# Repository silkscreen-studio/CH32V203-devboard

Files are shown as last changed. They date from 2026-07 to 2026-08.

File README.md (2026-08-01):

# CH32V203 devboard

A simple CH32V203C8U6 devboard, with a 7x8 charlieplexed matrix and a 12P FPC for IOs, beside the more common 2.54 headers for breadboard compatibility.
<br></br>

ZINE V1 1

# Key features 
 - CH32V203C8U6 MCU:
    - FLASH: 64k (+224K non-zero-wait program memory)
    - SRAM: 20k
    - 144MHz CPU max clock speed
    - 37 GPIOs
    - Many peripherals (4x USART, 2x SPI, 2x I2C, 1x CAN, USB (FS))
    - 9 analog capable GPIOs
    - 12 PWM capable GPIOs
 - USB-C for programming, USB device/host emulation, and power
 - 7x8 charlieplexed LED matrix (8 GPIOs)
 - 23x 2.54mm header pins
 - 12P .5mm FPC for breaking out 9 more IOs
 - Boot and Reset Button
 - On board 3.3V LDO `TLV75733PDBVR`, 1A max current

Demo with the charlieplexed LED matrix in action:
https://youtube.com/shorts/uVbg5wJzLvo
<br></br>

<p align="center">
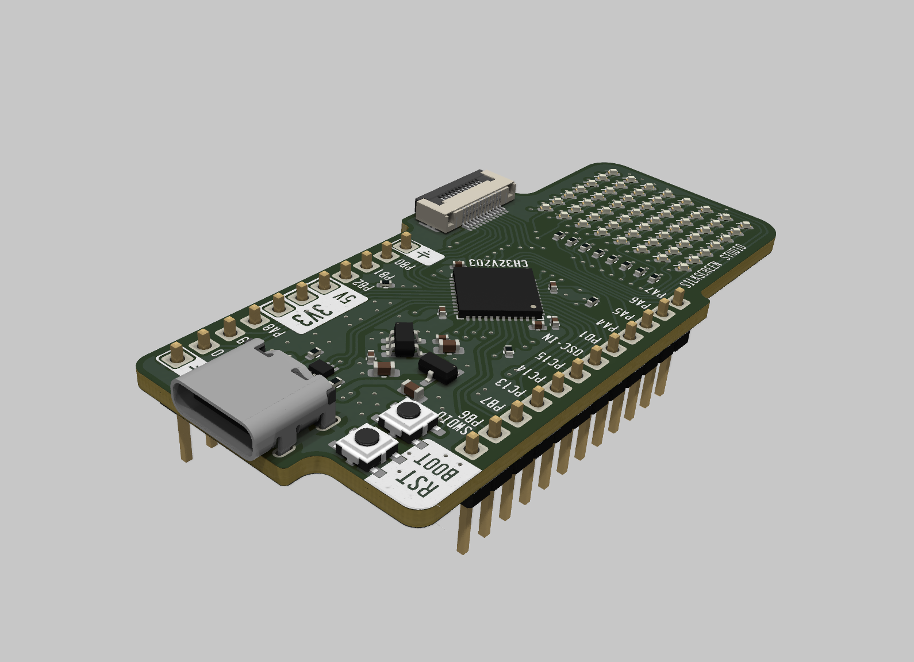
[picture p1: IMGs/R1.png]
Render 1

</p>
<p align="center">
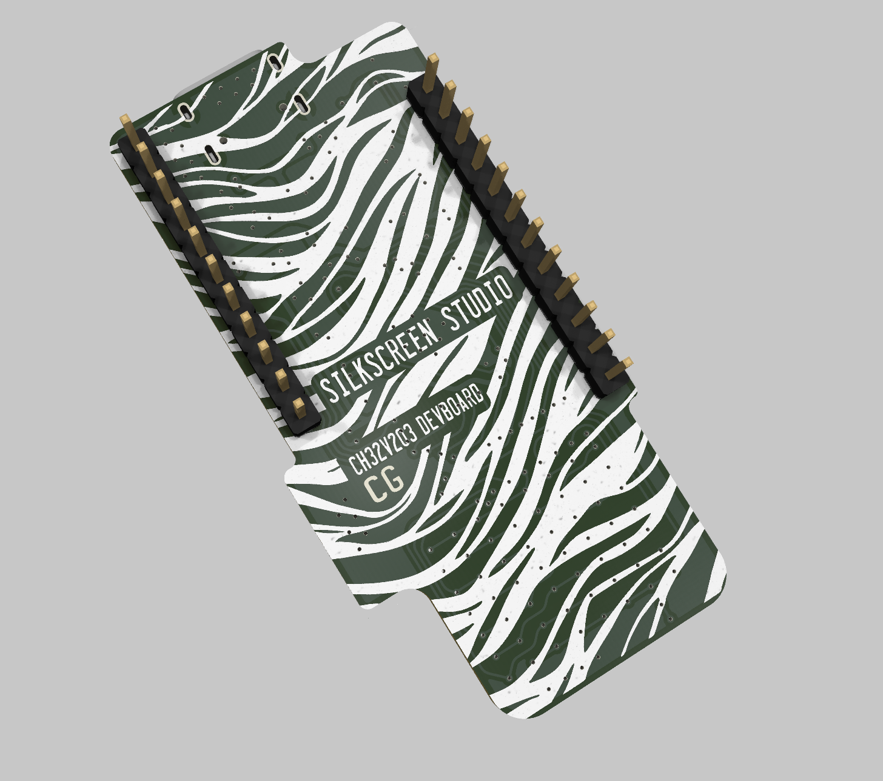
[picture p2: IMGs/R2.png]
Render 2
  
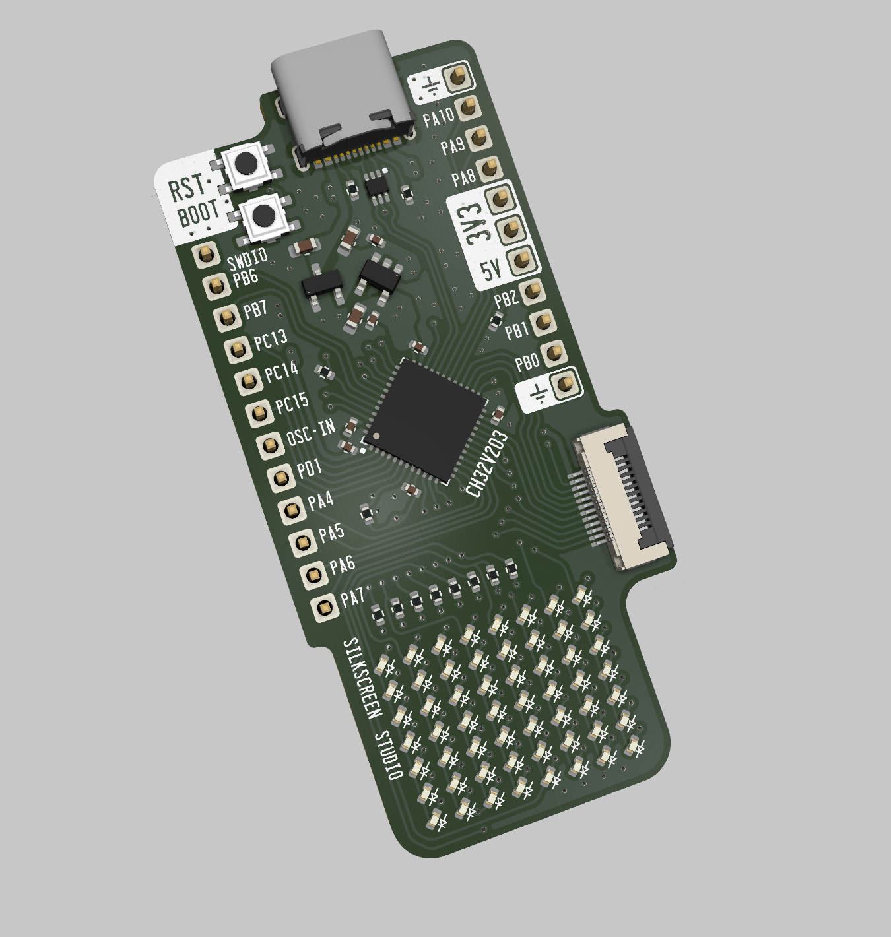
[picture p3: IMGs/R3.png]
Render 3
  
</p>

<p align="center">
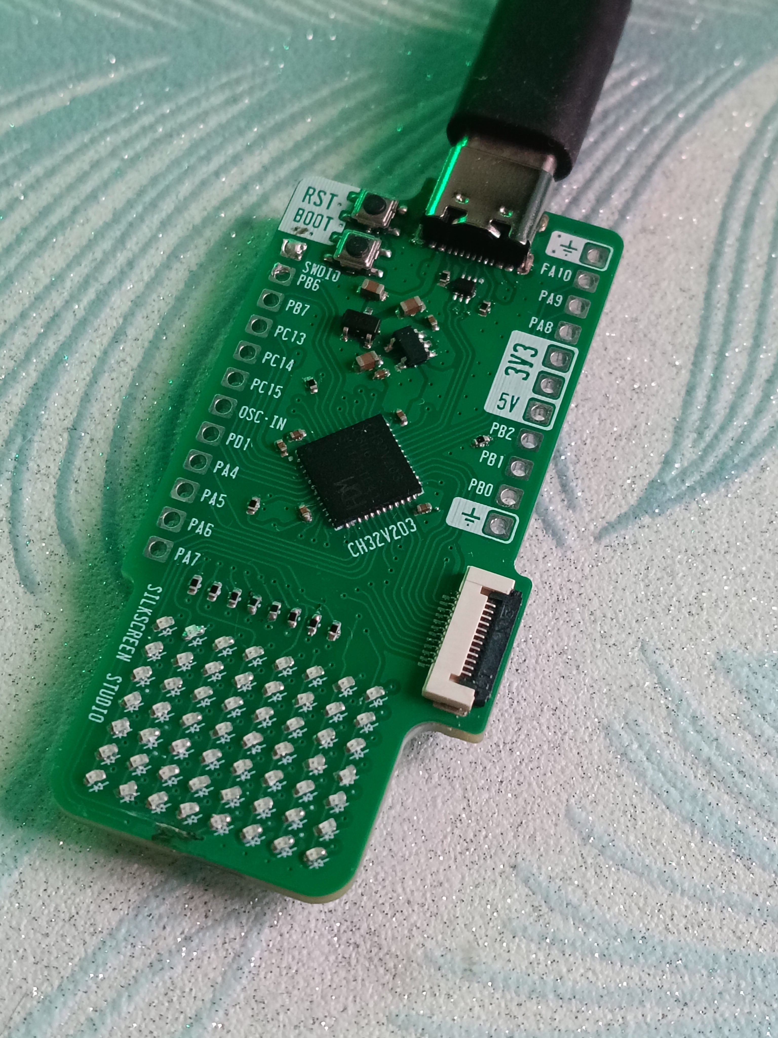
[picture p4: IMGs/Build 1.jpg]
Build 1

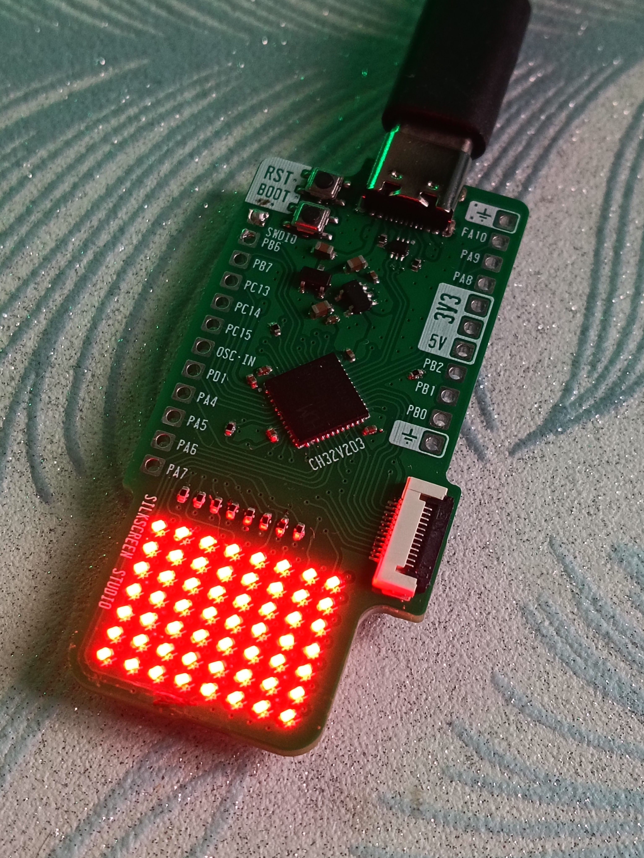
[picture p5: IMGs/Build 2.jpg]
Build 1

</p>

<br></br>

# Schematic
SCHEMATIC
<br></br>

# PCB layout
<p align="center">
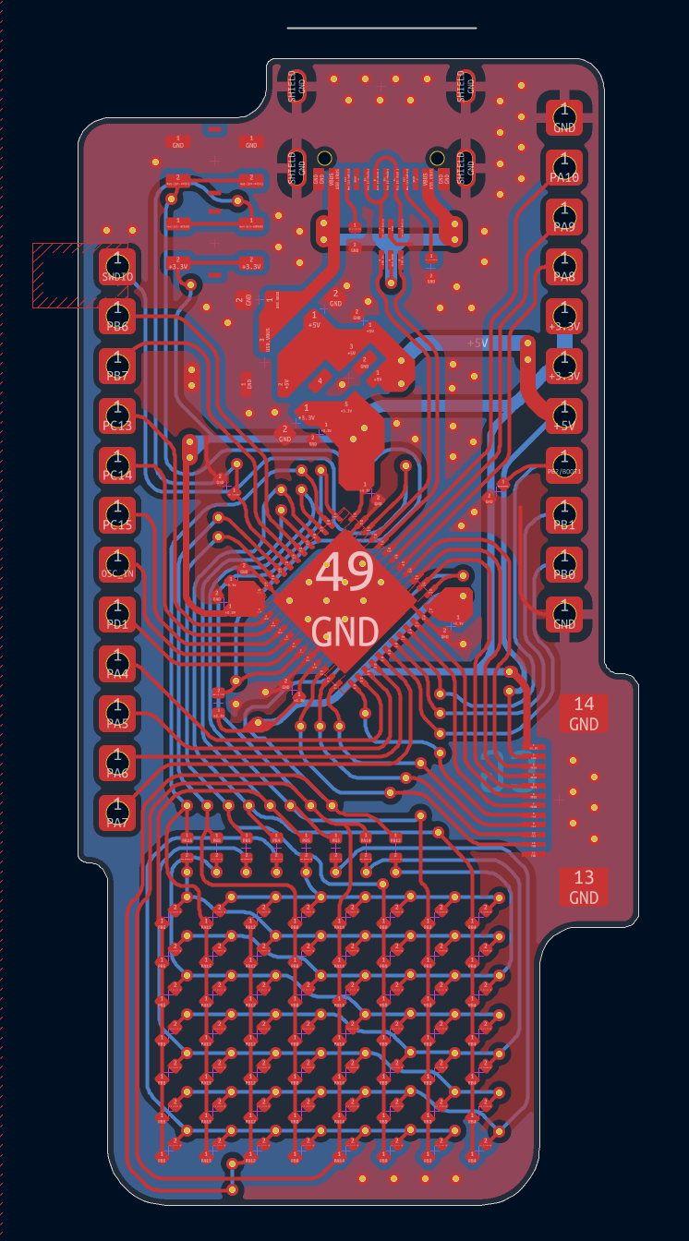
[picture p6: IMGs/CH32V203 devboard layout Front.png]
Layout F
  
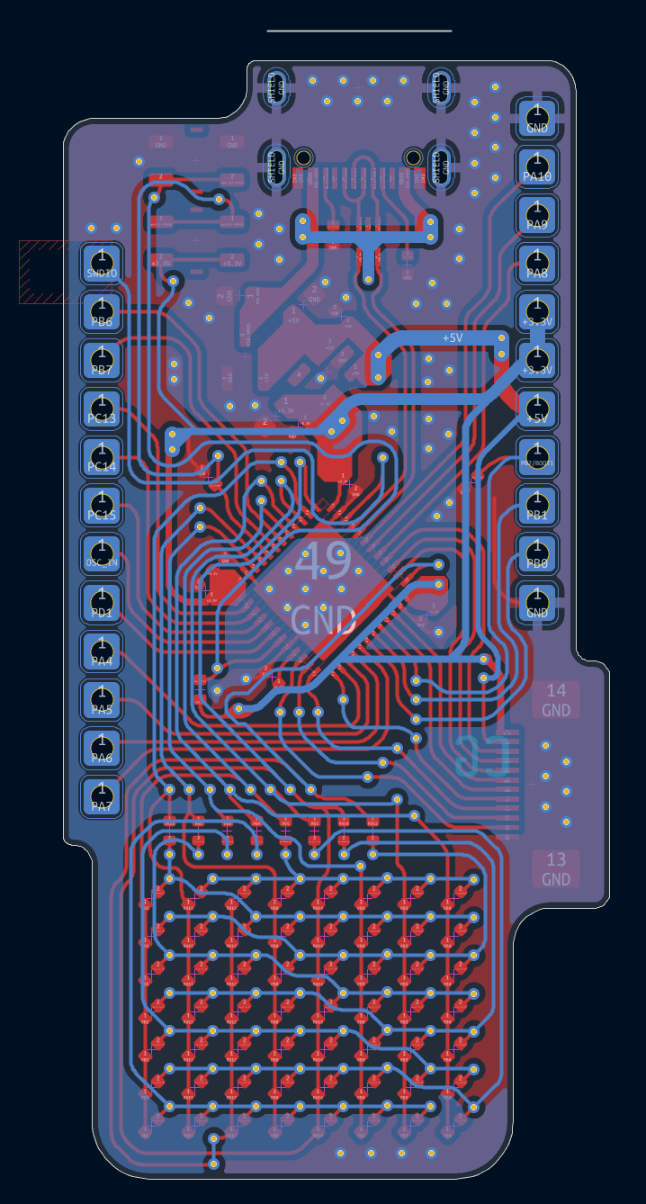
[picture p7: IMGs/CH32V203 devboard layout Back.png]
Layout B
  
</p>
<br></br>

# Pinout

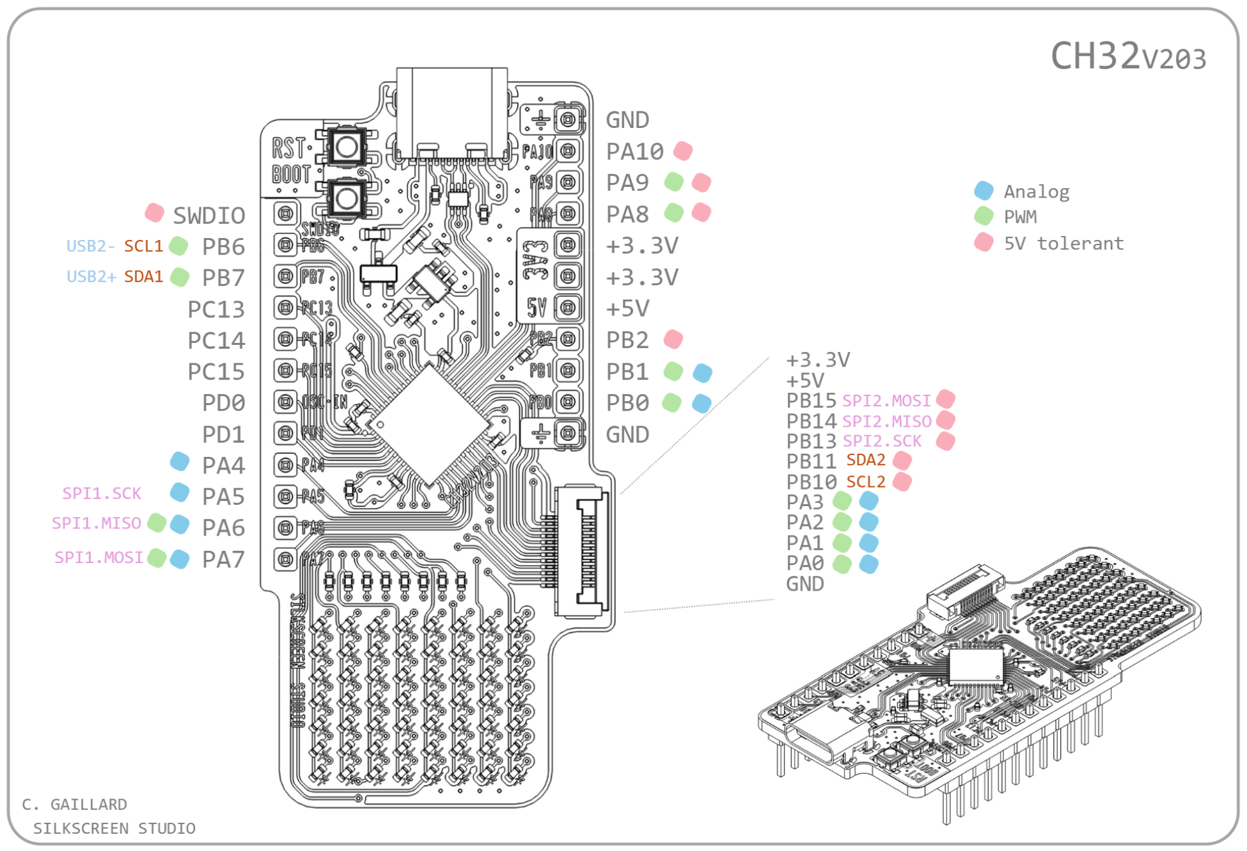
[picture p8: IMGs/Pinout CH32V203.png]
Pinout

<br></br>

# BOM

| Qty | Type | Part | Value | Extended description | Unit price | Price [MOQ]| LCSC part number | Link |
| --- | --- | --- | --- | --- | --- | --- | --- | --- |
| 7 | MLCC | CL05B104KB54PNC | 100nF | 0402 | $0.014 | $1.40 [100] | C307331 | https://www.lcsc.com/product-detail/C307331.html |
| 3 | MLCC | CL10A106MA8NRNC | 10µF | 0603 | $0.14 | $2.80 [20] | C96446 | https://www.lcsc.com/product-detail/C96446.html |
| 1 | Ideal Diode | CH213K | |  | $0.074 | $0.74 [10] | C5456874 | https://www.lcsc.com/product-detail/C5456874.html |
| 1 | FPC connector 12P | FPC-05F-12PH20 | |  | $0.11 | $0.57 [5] | C2856799 | https://www.lcsc.com/product-detail/C2856799.html |
| 56 | LED | XL-1005UOC | | Orange 0402 LED | $0.014 | $1.42 [100] | C965791 | https://www.lcsc.com/product-detail/C965791.html |
| 3 | Resistor | RC0402JR-7W10KL | 10k | 0402 SMD resistor | $0.004 | $0.45 [100] | C851859 | https://www.lcsc.com/product-detail/C851859.html |
| 2 | Resistor | RC-02K512JT | 5.1k | 0402 SMD resistor | $0.0033 | $0.33 [100] | C453708 | https://www.lcsc.com/product-detail/C453708.html |
| 8 | Resistor | RC0402FR-07680RL | 680 | 0402 SMD resistor | $0.0014 | $0.14 [100] | C137948 | https://www.lcsc.com/product-detail/C137948.html |
| 2 | Push button | TS-1075S-A1B2-D4 | | | $0.066 | $0.66 [10] | C492872 | https://www.lcsc.com/product-detail/C492872.html |
| 1 | MCU | CH32V203C8U6 | | | $0.85 | $0.85 [1] | C6407762 | https://www.lcsc.com/product-detail/C6407762.html |
| 1 | LDO | TLV75733PDBVR | | 3.3V LDO | $0.18 | $0.92 [5] | C485517 | https://www.lcsc.com/product-detail/C485517.html |
| 1 | ESD protection | USBLC6-2P6 | | | $0.28 | $1.39 [5] | C15999 | https://www.lcsc.com/product-detail/C15999.html |
| 1 | PCB | | | | $5 |  |  | https://jlcpcb.com/quote |
|  |  |  |  |  |  |  |  |  |
|  | TOTAL (price per board) | | | | $7.96 |  |  |  |
|  | TOTAL (price due to MOQ) | | | | $16.67 |  |  |  |

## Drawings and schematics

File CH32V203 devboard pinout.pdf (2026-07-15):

## CH32V203

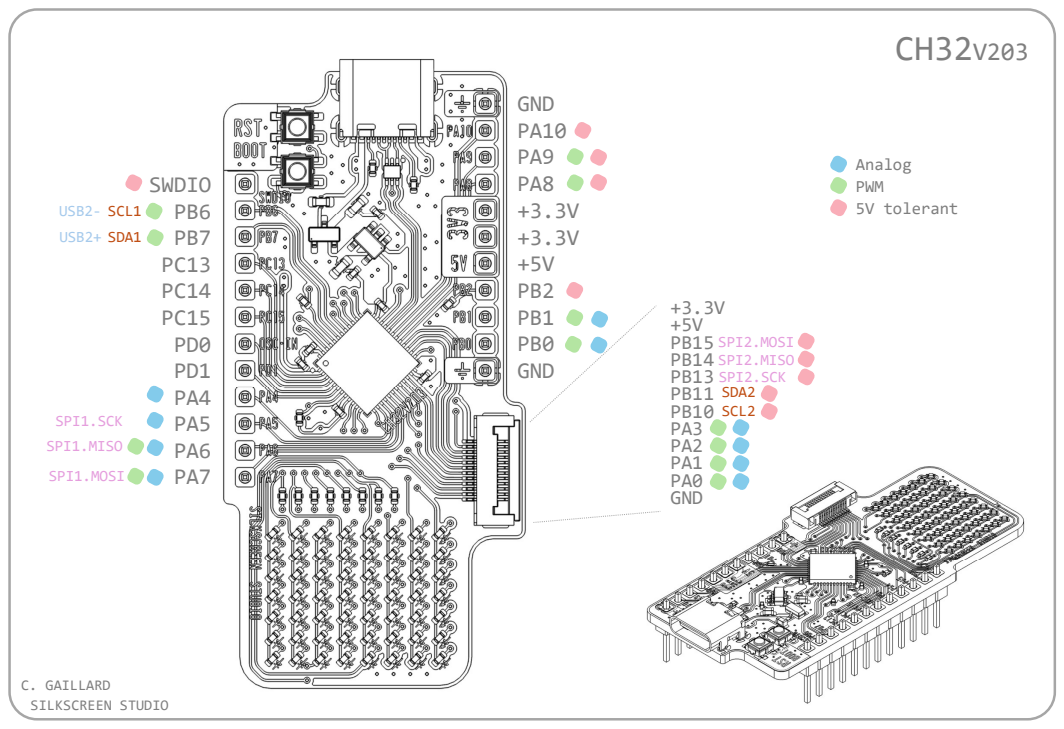
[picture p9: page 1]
GND; 5V tolerant; PWM; Analog; SILKSCREEN STUDIO; C. GAILLARD; PB2 PB1 PB0 GND; SWDIO PB6 PB7 PC13 PC14 PC15 PD0 PD1 PA4 PA5 PA6 PA7; +3.3V +5V PB15 PB14 PB13 PB11 PB10 PA3 PA2 PA1 PA0 GND; SDA2 SCL2; SDA1; USB2- SCL1 USB2+; SPI2.MOSI SPI2.MISO SPI2.SCK; SPI1.MOSI; SPI1.MISO; SPI1.SCK

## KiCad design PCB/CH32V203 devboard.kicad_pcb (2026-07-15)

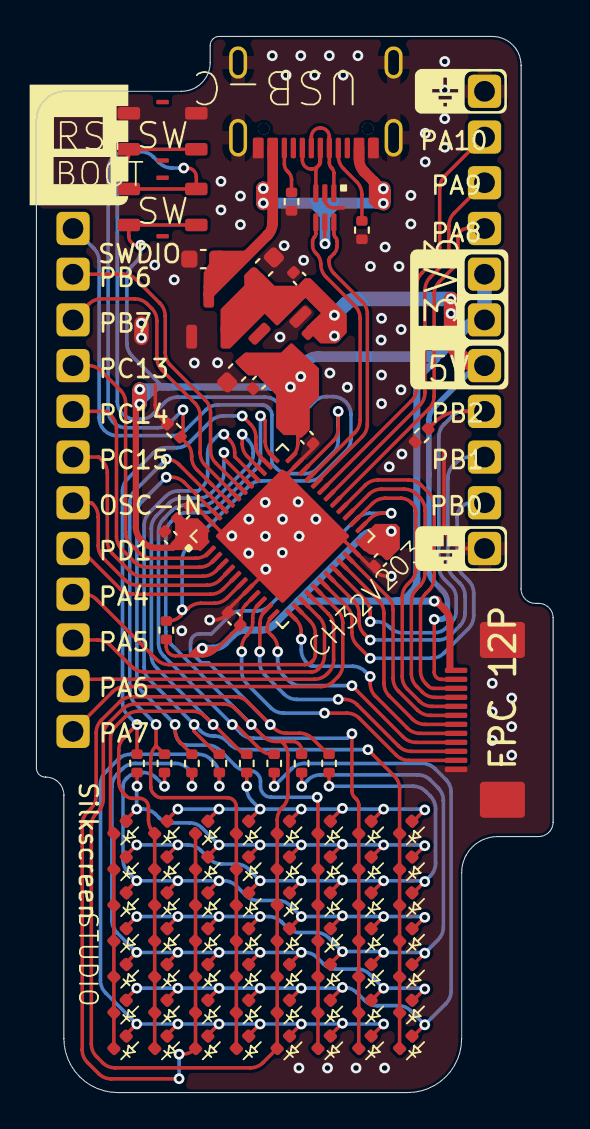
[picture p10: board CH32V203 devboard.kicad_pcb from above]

Board: 2 copper layers, 28.7 x 58.7 mm, 110 parts (0 on the bottom side), 55 nets.

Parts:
C1, C2, C3, C4, C5, C6, C9: 100nF; C_0402_1005Metric
C7, C8, C10: 10uF; C_0603_1608Metric
D1: SOT-23-3
FPC1: FPC 12P Custom footprint C2856799
J1: USB C connector USB2.0 16P; USB_C_16P_custom_footprint_C2765186
LED2, LED3, LED4, LED5, LED6, LED7, LED8, LED9, LED11, LED12, LED13, LED14, LED15, LED16, LED17, LED18, LED20, LED21, LED22, LED23, LED24, LED25, LED26, LED27, LED29, LED30, LED31, LED32, LED33, LED34, LED35, LED36, LED38, LED39, LED40, LED41, LED42, LED43, LED44, LED45, LED47, LED48, LED49, LED50, LED51, LED52, LED53, LED54, LED56, LED57, LED58, LED59, LED60, LED61, LED62, LED63: LED; CUSTOM LED_0402_1005Metric
P1, P2, P3, P4, P5, P6, P7, P8, P9, P10, P12, P13, P18, P19, P20, P21, P22, P23, P26, P27, P28, P29, P30: Custom 1P 2.54mm header
R1, R2, R3: 10k; R_0402_1005Metric
R4, R5: 5.1k; R_0402_1005Metric
R6, R7, R8, R9, R10, R11, R12, R13: 680; R_0402_1005Metric
SW1, SW2: SW_Push; switch_custom_footprint_TS-1075S-A1B2-D4_C492872.pretty
U1: CUSTOM_QFN-48-1EP_7x7mm_P0.5mm_EP5.3x5.3mm
U2: SOT-23-5
U3: USBLC6-2P6; USB ESD SOT666 C15999

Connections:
+3.3V: C1.1, C2.1, C3.1, C4.1, C5.1, C8.1, C9.1, FPC1.1, P18.1, P19.1, R1.1, SW2.2, U1.1 (VBAT), U1.9 (VDDA), U1.24 (VDD_VIO_1), U1.36 (VDD_2), U1.48 (VDD_VIO_3), U2.5 (OUT)
+5V: C6.1, C7.1, D1.2 (OUT+), FPC1.2, P20.1, U2.1 (IN), U2.3 (EN)
/USB.VBUS: C10.1, D1.3 (IN+), J1.VBUS (VBUS_VBUS), U3.5 (VBUS)
GND: C1.2, C2.2, C3.2, C4.2, C5.2, C6.2, C7.2, C8.2, C9.2, C10.2, D1.1 (GND), FPC1.12, FPC1.13 (SH1), FPC1.14 (SH2), J1.GND (GND_GND), J1.SHIELD (SHIELD_SH), P12.1, P13.1, R2.2, R3.2, R4.2, R5.2, SW1.1, U1.8 (VSSA), U1.23 (VSS_1), U1.35 (VSS_2), U1.47 (VSS_3), U1.49 (VSS), U2.2 (GND), U3.2 (GND)
unnamed: J1.CC1 (CC1_CC1), R5.1
unnamed: J1.CC2 (CC2_CC2), R4.1
unnamed: J1.D+ (D+_D+), U3.3 (I/O2)
unnamed: J1.D- (D-_D-), U3.1 (I/O1)
unnamed: LED3.2 (A), LED11.2 (A), LED27.2 (A), LED35.2 (A), LED43.2 (A), LED51.2 (A), LED59.2 (A), R8.2
unnamed: LED4.2 (A), LED12.2 (A), LED20.2 (A), LED36.2 (A), LED44.2 (A), LED52.2 (A), LED60.2 (A), R9.2
unnamed: LED5.2 (A), LED13.2 (A), LED21.2 (A), LED29.2 (A), LED45.2 (A), LED53.2 (A), LED61.2 (A), R10.2
unnamed: LED6.2 (A), LED14.2 (A), LED22.2 (A), LED30.2 (A), LED38.2 (A), LED54.2 (A), LED62.2 (A), R11.2
unnamed: LED7.2 (A), LED15.2 (A), LED23.2 (A), LED31.2 (A), LED39.2 (A), LED47.2 (A), LED63.2 (A), R12.2
unnamed: LED8.2 (A), LED16.2 (A), LED24.2 (A), LED32.2 (A), LED40.2 (A), LED48.2 (A), LED56.2 (A), R13.2
unnamed: LED9.2 (A), LED17.2 (A), LED25.2 (A), LED33.2 (A), LED41.2 (A), LED49.2 (A), LED57.2 (A), R6.2
unnamed: LED2.2 (A), LED18.2 (A), LED26.2 (A), LED34.2 (A), LED42.2 (A), LED50.2 (A), LED58.2 (A), R7.2
unnamed: R2.1, SW2.1, U1.44 (BOOT0)
unnamed: R1.2, SW1.2, U1.7 (NRST)
OSC_IN: P4.1, U1.5 (OSC_IN/PD0)
PA0: FPC1.11, U1.10 (PA0/WKUP/ADC0/TIM2_CH1)
PA1: FPC1.10, U1.11 (PA1/ADC1/TIM2_CH2)
PA2: FPC1.9, U1.12 (PA2/ADC2/TIM2_CH3/TX2)
PA3: FPC1.8, U1.13 (PA3/ADC3/TIM2_CH4/RX2)
PA4: P6.1, U1.14 (PA4/ADC4)
PA5: P7.1, U1.15 (PA5/ADC5/SPI1_SCK)
PA6: P8.1, U1.16 (PA6/ADC6/SPI1_MISO/TIM3_CH1)
PA7: P9.1, U1.17 (PA7/ADC7/SPI1_MOSI/TIM3_CH2)
PA8: P26.1, U1.29 (TIM1_CH1/PA8)
PA9: P27.1, U1.30 (TX1/TIM1_CH2/PA9)
PA10: P28.1, U1.31 (RX1/TIM1_CH3/PA10)
PA14: LED33.1 (K), LED34.1 (K), LED35.1 (K), LED36.1 (K), LED38.1 (K), LED39.1 (K), LED40.1 (K), R10.1, U1.37 (SWCLK/PA14)
PA15: LED9.1 (K), LED11.1 (K), LED12.1 (K), LED13.1 (K), LED14.1 (K), LED15.1 (K), LED16.1 (K), R7.1, U1.38 (PA15)
PB0: P21.1, U1.18 (PB0/ADC8/TIM3_CH3/TX4)
PB1: P22.1, U1.19 (PB1/ADC9/TIM3_CH4/RX4)
PB2/BOOT1: P10.1, R3.1, U1.20 (PB2/BOOT1)
PB3: LED49.1 (K), LED50.1 (K), LED51.1 (K), LED52.1 (K), LED53.1 (K), LED54.1 (K), LED56.1 (K), R12.1, U1.39 (PB3)
PB4: LED57.1 (K), LED58.1 (K), LED59.1 (K), LED60.1 (K), LED61.1 (K), LED62.1 (K), LED63.1 (K), R13.1, U1.40 (PB4)
PB5: LED2.1 (K), LED3.1 (K), LED4.1 (K), LED5.1 (K), LED6.1 (K), LED7.1 (K), LED8.1 (K), R6.1, U1.41 (PB5)
PB6: P29.1, U1.42 (TIM4_CH1/SCL1/PB6/USB2DM)
PB7: P30.1, U1.43 (TIM4_CH2/SDA1/PB7/USB2DP)
PB8: LED25.1 (K), LED26.1 (K), LED27.1 (K), LED29.1 (K), LED30.1 (K), LED31.1 (K), LED32.1 (K), R9.1, U1.45 (TIM4_CH3/PB8)
PB9: LED41.1 (K), LED42.1 (K), LED43.1 (K), LED44.1 (K), LED45.1 (K), LED47.1 (K), LED48.1 (K), R11.1, U1.46 (TIM4_CH4/PB9)
PB10: FPC1.7, U1.21 (PB10/SCL2/TX3)
PB11: FPC1.6, U1.22 (PB11/SDA2/RX3)
PB12: LED17.1 (K), LED18.1 (K), LED20.1 (K), LED21.1 (K), LED22.1 (K), LED23.1 (K), LED24.1 (K), R8.1, U1.25 (PB12)
PB13: FPC1.5, U1.26 (SPI2_SCK/PB13)
PB14: FPC1.4, U1.27 (SPI2_MISO/PB14)
PB15: FPC1.3, U1.28 (SPI2_MOSI/PB15)
PC13: P1.1, U1.2 (PC13/TAMPER_RTC)
PC14: P2.1, U1.3 (PC14/OSC32IN)
PC15: P3.1, U1.4 (PC15/OSC32OUT)
PD1: P5.1, U1.6 (OSC_OUT/PD1)
SWDIO: P23.1, U1.34 (SWDIO/PA13)
USB.D+: U1.33 (CAN_TX1/PA12/USB1DP), U3.4 (I/O2)
USB.D-: U1.32 (TIM1_CH4/CAN_RX1/PA11/USB1DM), U3.6 (I/O1)

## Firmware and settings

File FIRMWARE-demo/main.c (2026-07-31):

/*
 *   CH32V203 devboard demo code | Silkscreen Studio | by C.G. | https://github.com/silkscreen-studio/CH32V203-devboard
 *   Charlieplexed 7x8 LED matrix
 *
 *   After creating a new Mounriver Studio project and selecting the chip 'CH32V203C8U', the following main.c file can be replaced with the following code (in User>main.c)
 *   as the devboard doesn't comes with an external oscillator, the file 'system_ch32v20x.c has to be modified, changing the code as below:
 *            //#define SYSCLK_FREQ_HSE    HSE_VALUE
 *            //#define SYSCLK_FREQ_48MHz_HSE  48000000
 *            //#define SYSCLK_FREQ_56MHz_HSE  56000000
 *            //#define SYSCLK_FREQ_72MHz_HSE  72000000
 *            //#define SYSCLK_FREQ_96MHz_HSE  96000000             Default line that should be commented
 *            //#define SYSCLK_FREQ_120MHz_HSE  120000000
 *            //#define SYSCLK_FREQ_144MHz_HSE  144000000
 *            //#define SYSCLK_FREQ_HSI    HSI_VALUE
 *            //#define SYSCLK_FREQ_48MHz_HSI  48000000
 *            //#define SYSCLK_FREQ_56MHz_HSI  56000000
 *            //#define SYSCLK_FREQ_72MHz_HSI  72000000
 *            //#define SYSCLK_FREQ_96MHz_HSI  96000000
 *            //#define SYSCLK_FREQ_120MHz_HSI  120000000
 *            #define SYSCLK_FREQ_144MHz_HSI  144000000           // This line can be uncommented (or any other HSI line)
 */

#include "debug.h"


uint32_t DELAY_FRAME = 1000000;  // 1000 ms
uint8_t stateLED = 0;

typedef struct {
    GPIO_TypeDef *PORT;
    uint16_t PIN;
} PinSetup;

PinSetup pinMap[] = {

    {GPIOB, GPIO_Pin_5 }, //  0  L1
    {GPIOA, GPIO_Pin_15}, //  1  L2
    {GPIOB, GPIO_Pin_12}, //  2  L3
    {GPIOB, GPIO_Pin_8 }, //  3  L4
    {GPIOA, GPIO_Pin_14}, //  4   L5
    {GPIOB, GPIO_Pin_9 }, //  5   L6
    {GPIOB, GPIO_Pin_3 }, //  6   L7
    {GPIOB, GPIO_Pin_4 }, //  7   L8

    {GPIOB, GPIO_Pin_15}, // 8   FPC 1
    {GPIOB, GPIO_Pin_14}, // 9    .
    {GPIOB, GPIO_Pin_13}, // 10   .
    {GPIOB, GPIO_Pin_11}, // 11
    {GPIOB, GPIO_Pin_10}, // 12
    {GPIOA, GPIO_Pin_3 }, // 13
    {GPIOA, GPIO_Pin_2 }, // 14   .
    {GPIOA, GPIO_Pin_1 }, // 15   .
    {GPIOA, GPIO_Pin_0 }, // 16  FPC 9

    {GPIOC, GPIO_Pin_13}, // 17
    {GPIOC, GPIO_Pin_14}, // 18
    {GPIOC, GPIO_Pin_15}, // 19
    {GPIOD, GPIO_Pin_1 }, // 20
    {GPIOA, GPIO_Pin_4 }, // 21
    {GPIOA, GPIO_Pin_5 }, // 22
    {GPIOA, GPIO_Pin_6 }, // 23
    {GPIOA, GPIO_Pin_7 }, // 24
    {GPIOB, GPIO_Pin_2 }, // 25
    {GPIOB, GPIO_Pin_0 }, // 21
    {GPIOB, GPIO_Pin_1 }, // 22
    {GPIOB, GPIO_Pin_7 }, // 23
    {GPIOB, GPIO_Pin_6 }, // 24
    {GPIOA, GPIO_Pin_8 }, // 25
    {GPIOA, GPIO_Pin_9 }, // 26
    {GPIOA, GPIO_Pin_10}, // 27
};

// Any LED matrix pattern can be displayed with 7 bytes arrays. It could also be updated from SPI/I2C/USB where I packet for 1 frame needs 7 bytes.

static const uint8_t FULL_ON[7] = {
    0b11111111,
    0b11111111,
    0b11111111,
    0b11111111,
    0b11111111,
    0b11111111,
    0b11111111,
};

static const uint8_t CHECKERBOARD[7] = {
    0b10101010,
    0b01010101,
    0b10101010,
    0b01010101,
    0b10101010,
    0b01010101,
    0b10101010,
};

static const uint8_t FULL_OFF[7] = {
    0b00000001,
    0b00000000,
    0b00000000,
    0b00000000,
    0b00000000,
    0b00000000,
    0b00000000,
};

static const uint8_t SMILEY[7] = {
    0b00000000,
    0b01100110,
    0b01100110,
    0b00000000,
    0b01000010,
    0b00111100,
    0b00000000,
};

static const uint8_t CHECKMARK[7] = {
    0b00000000,
    0b00000011,
    0b00000110,
    0b11001100,
    0b01111000,
    0b01110000,
    0b00100000,
};

uint8_t slidingLine[7] = {
    0b00000001,
    0b00000010,
    0b00000100,
    0b00001000,
    0b00010000,
    0b00100000,
    0b01000000,
};

void pinMode (uint8_t pin_number, GPIOMode_TypeDef mode) {
    if (pin_number > 27)
        return;

    GPIO_InitTypeDef GPIO_InitStructure = {0};
    RCC_APB2PeriphClockCmd (RCC_APB2Periph_GPIOA | RCC_APB2Periph_GPIOB | RCC_APB2Periph_GPIOC | RCC_APB2Periph_GPIOD, ENABLE);

    GPIO_InitStructure.GPIO_Pin = pinMap[pin_number].PIN;
    GPIO_InitStructure.GPIO_Mode = mode;
    GPIO_InitStructure.GPIO_Speed = GPIO_Speed_50MHz;

    GPIO_Init (pinMap[pin_number].PORT, &GPIO_InitStructure);
}

void digitalWrite (uint8_t pin_number, uint8_t bit_state) {
    if (pin_number > 27)
        return;
    if (bit_state == 1) {
        GPIO_SetBits (pinMap[pin_number].PORT, pinMap[pin_number].PIN);
    } else {
        GPIO_ResetBits (pinMap[pin_number].PORT, pinMap[pin_number].PIN);
    }
}

uint8_t digitalRead (uint8_t pin_number) {
    if (pin_number > 27)
        return 0;
    return GPIO_ReadInputDataBit (pinMap[pin_number].PORT, pinMap[pin_number].PIN);
}

void updateDisplay (const uint8_t LED_Matrix[7]) {

    for (uint8_t c = 0; c < 8; c++) {
        pinMode (c, GPIO_Mode_Out_PP);
        digitalWrite (c, 0);

        for (uint8_t l = 0; l < 8; l++) {

            if (l > c) {
                uint8_t bit = (LED_Matrix[l - 1] >> (8 - c - 1)) & 0b0000001;
                if (bit == 1) {
                    pinMode (l, GPIO_Mode_Out_PP);
                    digitalWrite (l, 1);
                }
            }

            if (l < c) {
                uint8_t bit = (LED_Matrix[l] >> (8 - c - 1)) & 0b0000001;
                if (bit == 1) {
                    pinMode (l, GPIO_Mode_Out_PP);
                    digitalWrite (l, 1);
                }
            }
        }

        Delay_Us (DELAY_FRAME);
        for (uint8_t pin = 0; pin < 8; pin++) {
            pinMode (pin, GPIO_Mode_IN_FLOATING);
        }
    }
}

int main (void) {
    SystemCoreClockUpdate();
    Delay_Init();
    Delay_Ms (4000);
    RCC_APB2PeriphClockCmd (RCC_APB2Periph_AFIO, ENABLE);
    GPIO_PinRemapConfig (GPIO_Remap_SWJ_Disable, ENABLE);
    Delay_Ms (600);
    pinMode (0, GPIO_Mode_IN_FLOATING);
    pinMode (1, GPIO_Mode_IN_FLOATING);
    pinMode (2, GPIO_Mode_IN_FLOATING);
    pinMode (3, GPIO_Mode_IN_FLOATING);
    pinMode (4, GPIO_Mode_IN_FLOATING);
    pinMode (5, GPIO_Mode_IN_FLOATING);
    pinMode (6, GPIO_Mode_IN_FLOATING);
    pinMode (7, GPIO_Mode_IN_FLOATING);
    Delay_Ms (400);

    while (1) {
        for (uint16_t i = 0; i < 3000; i++) {
            updateDisplay (FULL_ON);
            if (DELAY_FRAME > 150) {
                DELAY_FRAME = DELAY_FRAME / 2;
            }
        }

        for (uint16_t i = 0; i < 3000; i++) {
            updateDisplay (CHECKMARK);
        }

        for (uint16_t i = 0; i < 60; i++) {
            for (uint8_t row = 0; row < 8; row++) {
                if (slidingLine[row] == 0b10000000) {
                    slidingLine[row] = 0b00000001;
                }
                else {
                    slidingLine[row] = slidingLine[row] * 2;
                }
                
            }
            for (uint16_t i = 0; i < 100; i++) {
                updateDisplay (slidingLine);
            }
        }

        for (uint16_t i = 0; i < 3000; i++) {
            updateDisplay (CHECKERBOARD);
        }

        for (uint16_t i = 0; i < 3000; i++) {
            updateDisplay (SMILEY);
        }
    }
}

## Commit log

2026-07-15 Added PCB design files
    [CH32V203 devboard.kicad_pcb, CH32V203 devboard.kicad_sch]
2026-07-31 Added Kicad library submodule
